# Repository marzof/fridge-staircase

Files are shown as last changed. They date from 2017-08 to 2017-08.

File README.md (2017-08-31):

Project for a staircase containing a fridge
-------

This repository contains all the files we made in order to build the staircase you see in the picture.



Every .fcstd file ([FreeCAD](https://www.freecadweb.org/) file) contains a 3d model of a part of the stair. Some of them contains an assemblage of parts as you can see in the dependency list at the end of this document (we used the [Assembly2 plugin](https://github.com/hamish2014/FreeCAD_assembly2)).

Drawing layout in *A101_assembled_stair.fcstd* and *A721_double_beam.fcstd* may not work correctly due to the excessive complexity of the board.
Because of that we decided, for the boards *A731*, *A732* and *A733* to compose the layout drawings into another software (we used [QCAD](http://qcad.org/en/)).

The workflow was:

1. model simple parts of the object in *FreeCAD*
2. render the drawing of the parts in *TechDraw* workbench. Here we set the point of view, the scale of the drawing, the width and the type of lines.
3. export the drawing in SVG (the dxf exporter doesn't seem to work very well)
4. convert the svg drawing in a series of dxf files using the [fc2dxf script](https://github.com/marzof/scripts/blob/master/fc2dxf.py): at the end you'll get a file for every style of line (visible, hidden, thick, thin...)
5. compose the board in a CAD software: add the title block, the dimensions, the annotations, etc...

You can find more pictures and infos [here](http://softwareliberoperlarchitettura.mfarchitetti.it/en_US/2017/08/31/progetto-per-una-scala-un-test-riuscito-per-un-software-open-source-per-la-progettazione-param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)

List of dependencies
----------

 - A101_assembled_stair.fcstd
	-  A712_fridge_box.fcstd
	-  step.fcstd
	-  plate.fcstd
	-  beam.fcstd
	-  railing_element.fcstd
	-  beam_plate.fcstd
	-  railing_last_element.fcstd
	-  railing_last_plate.fcstd
	-  railing_first_element.fcstd
	-  beam_ground_plate.fcstd
 - A711_fridge_box_panels.fcstd
	-  stair_profile.fcstd
	-  step.fcstd
	-  double_beam.fcstd
	-  fridge_box_door.fcstd
 - A712_fridge_box.fcstd
	-  fridge_box_door.fcstd
	-  A711_fridge_box_panels.fcstd
	-  fridge_box_door.fcstd
 - A721_double_beam.fcstd
	-  beam.fcstd
	-  A711_fridge_box_panels.fcstd
	-  stair_profile.fcstd
	-  step.fcstd
	-  beam_plate.fcstd
	-  fridge_box_door.fcstd
	-  railing_plate.fcstd
	-  plate.fcstd
 - all.fcstd
	-  double_beam.fcstd
	-  fasteners.fcstd
	-  railing_plate.fcstd
	-  railing_dist.fcstd
	-  railing_eyelet.fcstd
	-  railing_fasteners.fcstd
	-  ropes.fcstd
	-  step.fcstd
	-  handrail_holder.fcstd
	-  handrail.fcstd
	-  railing_wood.fcstd
	-  A711_fridge_box_panels.fcstd
	-  fridge_box_door.fcstd
	-  handrail_holder.fcstd
	-  railing_eyelet.fcstd
	-  railing_last_wood.fcstd
	-  stair_profile.fcstd
	-  room.fcstd
	-  plate.fcstd
	-  railing_last_steel.fcstd
	-  railing_plate.fcstd
	-  railing_dist.fcstd
	-  railing_eyelet.fcstd
	-  railing_fasteners.fcstd
	-  handrail_holder.fcstd
	-  railing_wood.fcstd
	-  handrail.fcstd
 - beam.fcstd
	-  stair_profile.fcstd
	-  step.fcstd
 - beam_ground_plate.fcstd
 - beam_plate.fcstd
	-  A711_fridge_box_panels.fcstd
	-  step.fcstd
	-  stair_profile.fcstd
	-  double_beam.fcstd
 - double_beam.fcstd
	-  beam.fcstd
	-  A711_fridge_box_panels.fcstd
	-  stair_profile.fcstd
	-  step.fcstd
	-  beam_plate.fcstd
	-  fridge_box_door.fcstd
	-  railing_plate.fcstd
	-  plate.fcstd
 - fasteners.fcstd
	-  double_beam.fcstd
	-  railing_plate.fcstd
 - fridge_box_door.fcstd
 - handrail.fcstd
 - handrail_holder.fcstd
	-  railing_eyelet.fcstd
 - loft_handrail.fcstd
 - loft_handrail_holder.fcstd
 - loft_railing_element.fcstd
	-  room.fcstd
 - loft_railing.fcstd
	-  handrail.fcstd
	-  A711_fridge_box_panels.fcstd
	-  fridge_box_door.fcstd
	-  handrail_holder.fcstd
	-  railing_eyelet.fcstd
	-  railing_last_wood.fcstd
	-  room.fcstd
	-  railing_last_steel.fcstd
	-  loft_railing_element.fcstd
	-  loft_ropes.fcstd
	-  railing_element.fcstd
	-  ropes.fcstd
	-  railing_last.fcstd
 - loft_ropes.fcstd
 - plate.fcstd
	-  step.fcstd
 - railing_dist.fcstd
	-  railing_eyelet.fcstd
 - railing_element.fcstd
	-  double_beam.fcstd
	-  fasteners.fcstd
	-  railing_plate.fcstd
	-  railing_dist.fcstd
	-  railing_eyelet.fcstd
	-  railing_fasteners.fcstd
	-  ropes.fcstd
	-  step.fcstd
	-  handrail_holder.fcstd
	-  handrail.fcstd
	-  railing_wood.fcstd
	-  A711_fridge_box_panels.fcstd
	-  fridge_box_door.fcstd
	-  handrail_holder.fcstd
	-  railing_eyelet.fcstd
	-  railing_last_wood.fcstd
	-  stair_profile.fcstd
	-  room.fcstd
	-  plate.fcstd
	-  room.fcstd
	-  railing_last_steel.fcstd
 - railing_eyelet.fcstd
 - railing_fasteners.fcstd
 - railing_last.fcstd
	-  handrail_holder.fcstd
	-  railing_eyelet.fcstd
	-  railing_last_wood.fcstd
	-  railing_last_steel.fcstd
 - railing_last_steel.fcstd
	-  railing_eyelet.fcstd
	-  room.fcstd
	-  loft_railing_element.fcstd
 - railing_last_wood.fcstd
	-  double_beam.fcstd
	-  railing_last_steel.fcstd
 - railing_plate.fcstd
	-  double_beam.fcstd
 - railing_wood.fcstd
 - room.fcstd
 - ropes.fcstd
	-  railing_eyelet.fcstd
 - stair_profile.fcstd
 - step.fcstd
	-  stair_profile.fcstd

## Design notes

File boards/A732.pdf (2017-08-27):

1 | 2 | 3 | 4 | 5 | 6 | 7 | 8 | 9 | 10 | 11 FEDCBAGH | FEDCABGH 1 | 2 | 3 | 4 | 5 | 6 | 7 | 8 | 9 | 10 | PROGETTO: | DATA COMMITTENTE: ARCHITETTI: OGGETTO: TAVOLA NO.: | DI SCALA: FORMATO: DATA: REV: LUOGO: NOTE: NOME FILE: VERSIONE mf architetti Milano - Italy Via Lario 13/A _ +39(0)269901138 mfarchitetti.it _ mail@mfarchitetti.it CASA VACANZE A SESTRI SCALA INTERNA MARZIA FILATRELLA MARCO FERRARA DETTAGLI PARAPETTO - A732.DXF 1.0 | 2017.05.11 6 | 7 (nd) A732 2017/05/11 1.0 | 1:5;1:10 A2 0 | 1/5 | 1/2 | 25cm;50cm 2850 | 865 1100 1100 1100 | 850 630 630 615 | 615 | 615 | 630 | 165 | 315 | 45 115 | 55 Il supporto per l'ultimo montante avverrà attraverso una piastra metallica a "L" fissata al soppalco durante la fase di posa in opera | ULTIMO MONTANTE Listelli in legno sp. 20mm no. pz. 1 coppia scala 1:5 SUPPORTO ULTIMO MONTANTE Piastra in acciaio sp. 6mm e sp. 10mm no. pz. 1 scala 1:5 | Foro posteriore filettato per occhiello reggi-cavi ³².5 45 180 45 180 45 180 45 112.5 | 865 50 | 50 ⁸⁶⁵

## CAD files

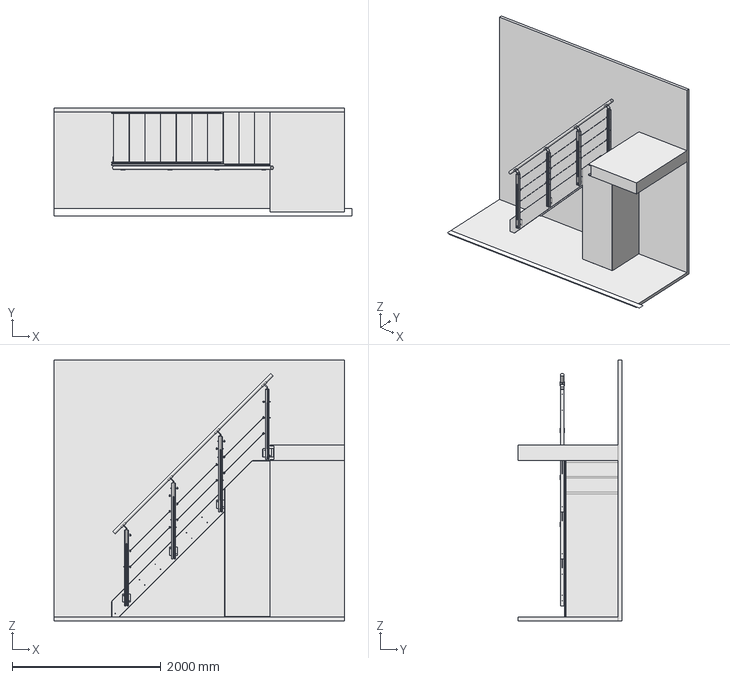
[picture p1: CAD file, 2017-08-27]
A101_assembled_stair.fcstd
4000.0 x 1445.0 x 3500.0 mm
all
Rectangle002

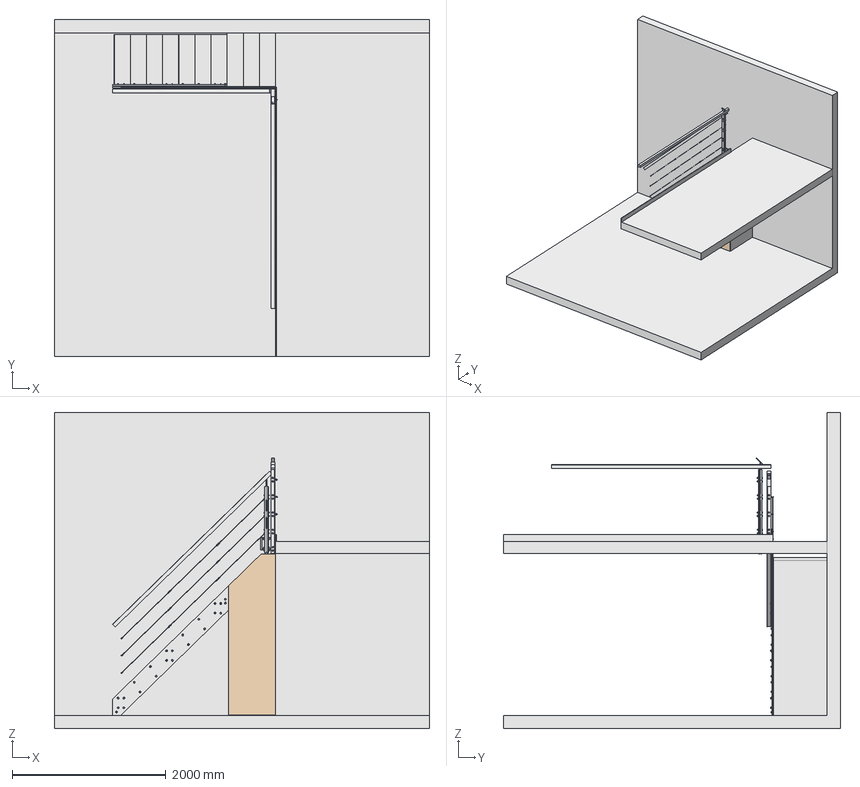
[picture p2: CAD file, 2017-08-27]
all.fcstd
4875.0 x 4375.4 x 4112.1 mm
double_beam_01
fasteners_01
step_01
handrail_01
ropes
fridge_box_panels_01
fridge_box_door_01
last_railing
room_01
plate_01
handrail_002

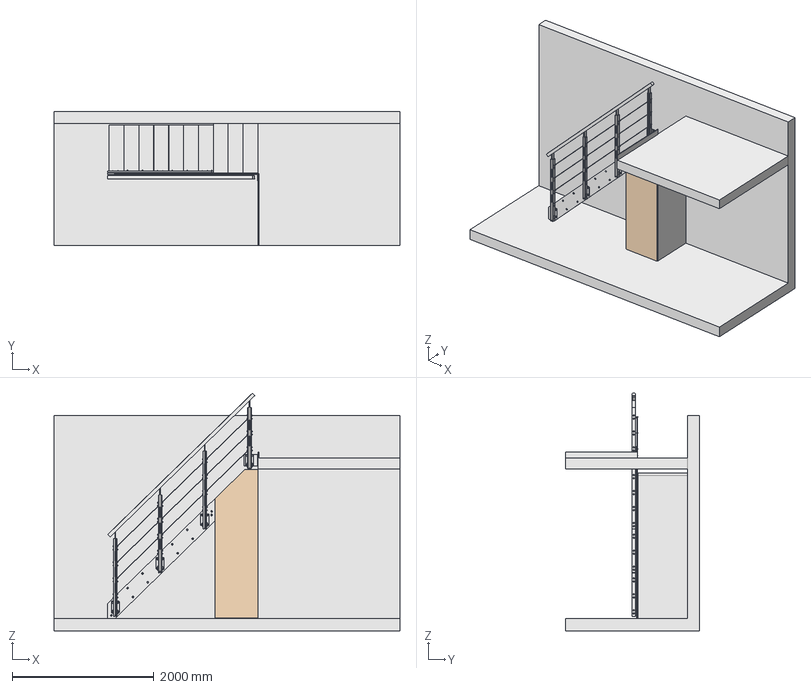
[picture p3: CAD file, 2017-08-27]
views/railing_last_element_rear.fcstd
4875.0 x 1890.4 x 3348.2 mm
double_beam_01
fasteners_01
step_01
ropes
fridge_box_panels_01
fridge_box_door_01
plate_01
Cutted_room
handrail_01
last_railing

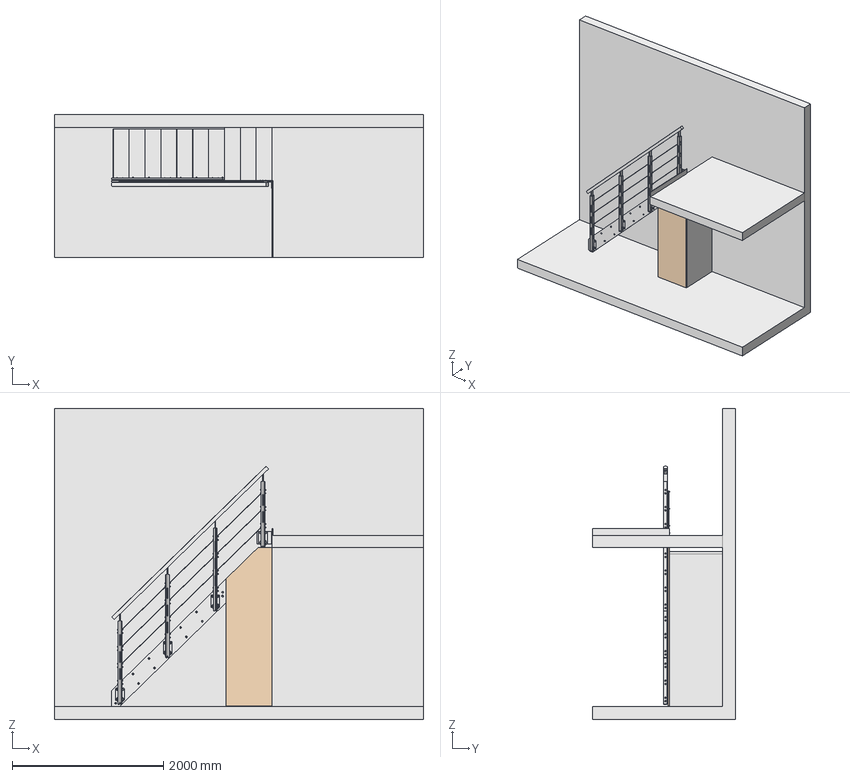
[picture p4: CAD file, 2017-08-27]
views/railing_element_rear.fcstd
4875.0 x 1890.4 x 4112.1 mm
double_beam_01
fasteners_01
step_01
ropes
fridge_box_panels_01
fridge_box_door_01
room_01
plate_01
handrail_01
last_railing

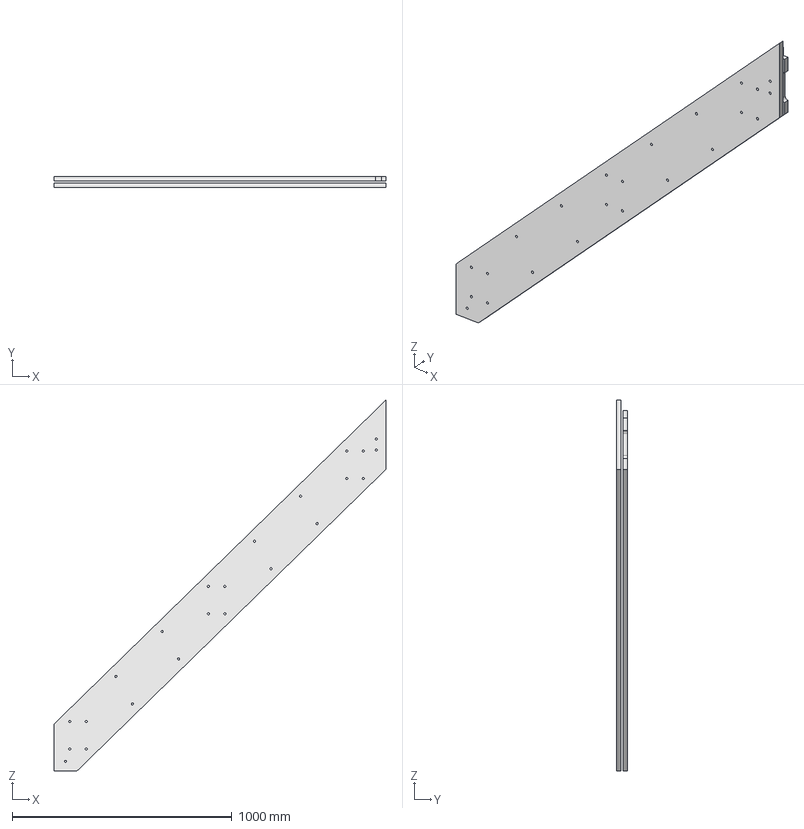
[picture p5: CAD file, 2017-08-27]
double_beam.fcstd
1510.0 x 50.0 x 1687.5 mm

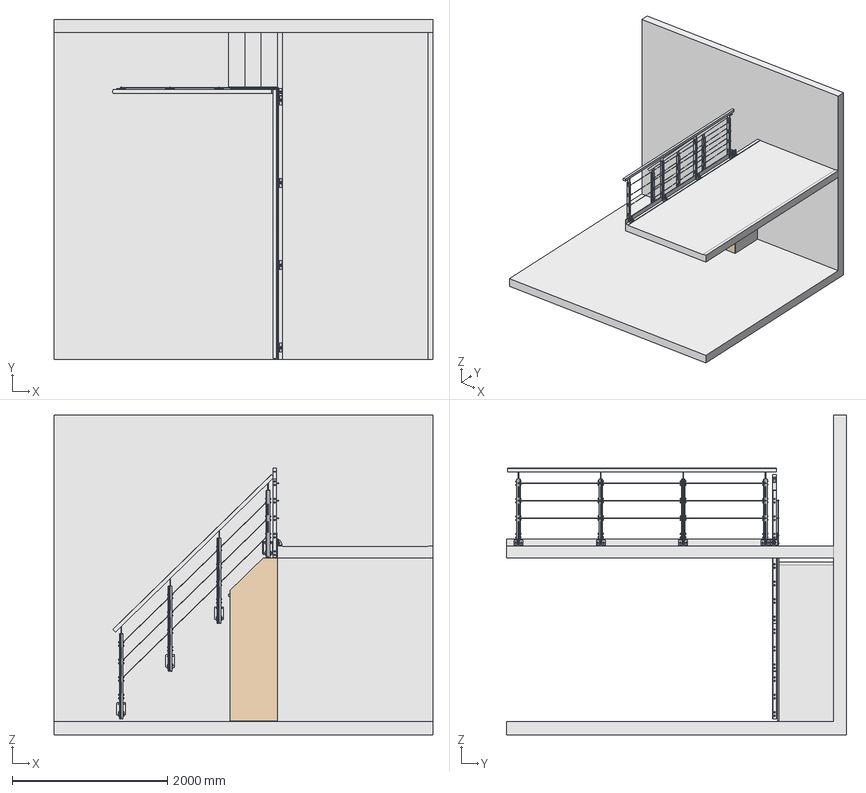
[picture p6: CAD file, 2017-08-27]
loft_railing.fcstd
4875.0 x 4375.4 x 4112.1 mm
loft_ropes_01
railing_element_01
room_01
fridge_box_door_01
fridge_box_panels_01
handrail_01
railing_last_01

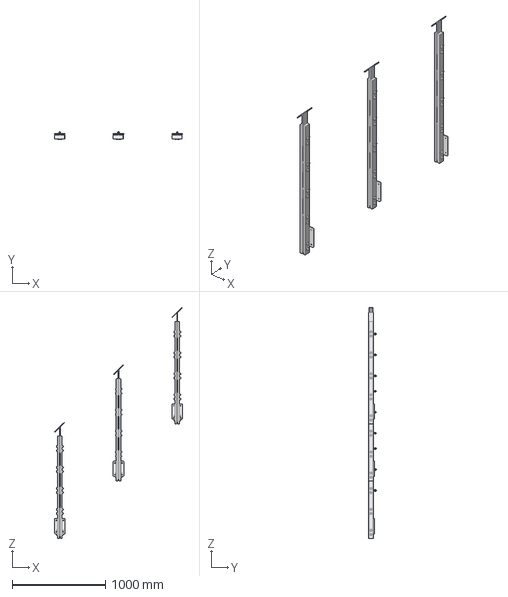
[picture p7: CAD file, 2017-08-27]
railing_element.fcstd
1375.4 x 83.2 x 2479.1 mm

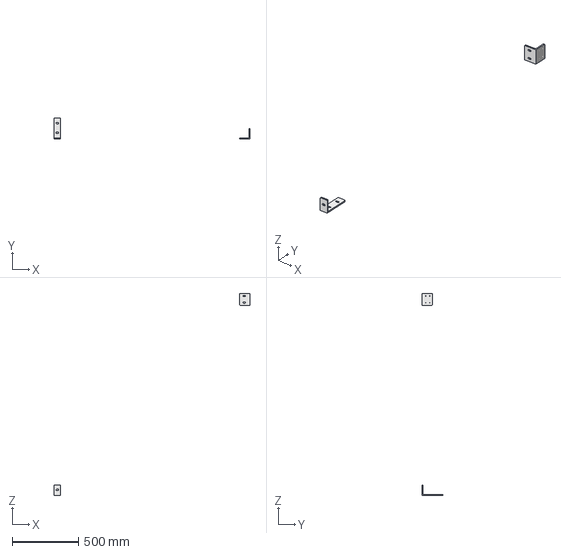
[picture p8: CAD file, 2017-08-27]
beam_plate.fcstd
1482.8 x 160.0 x 1530.0 mm

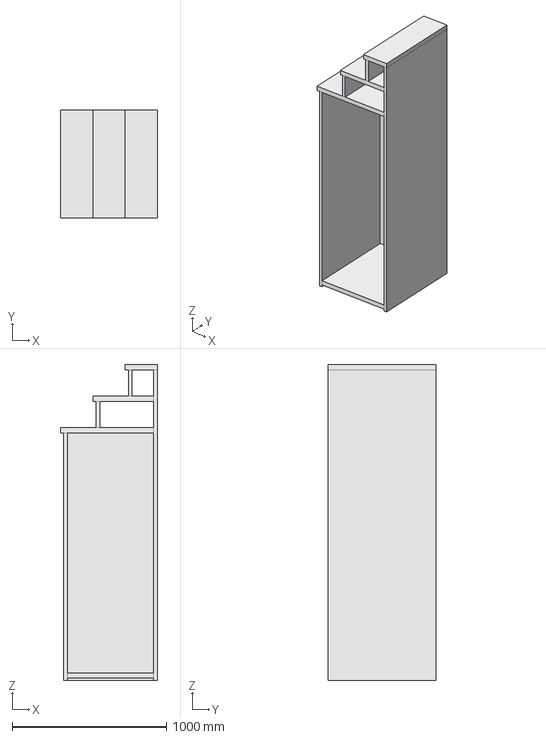
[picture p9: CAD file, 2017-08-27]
A711_fridge_box_panels.fcstd
630.0 x 700.0 x 2050.0 mm

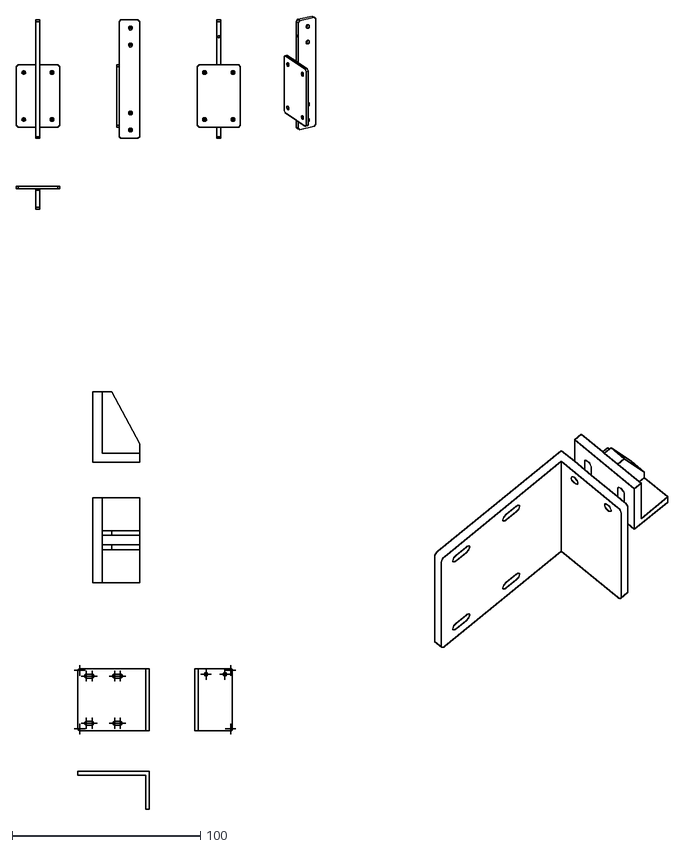
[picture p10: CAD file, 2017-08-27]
railing_last_elements_fll.dxf
345.8 x 420.8

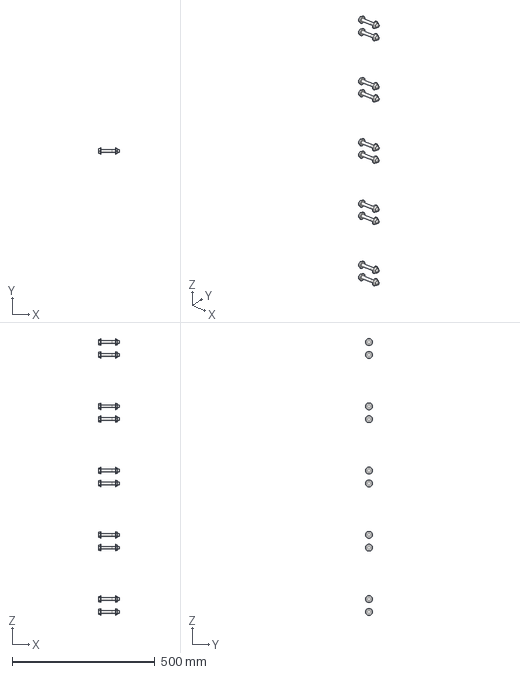
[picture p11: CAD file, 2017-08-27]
railing_fasteners.fcstd
72.4 x 25.0 x 970.0 mm

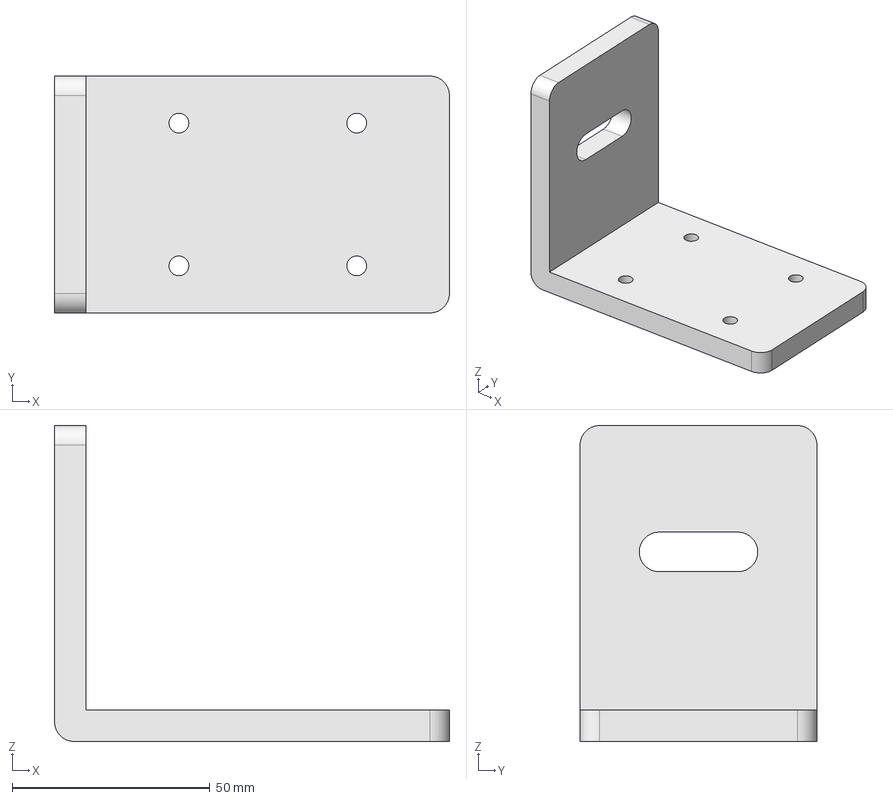
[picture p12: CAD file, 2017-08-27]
beam_ground_plate.fcstd
100.0 x 60.0 x 80.0 mm

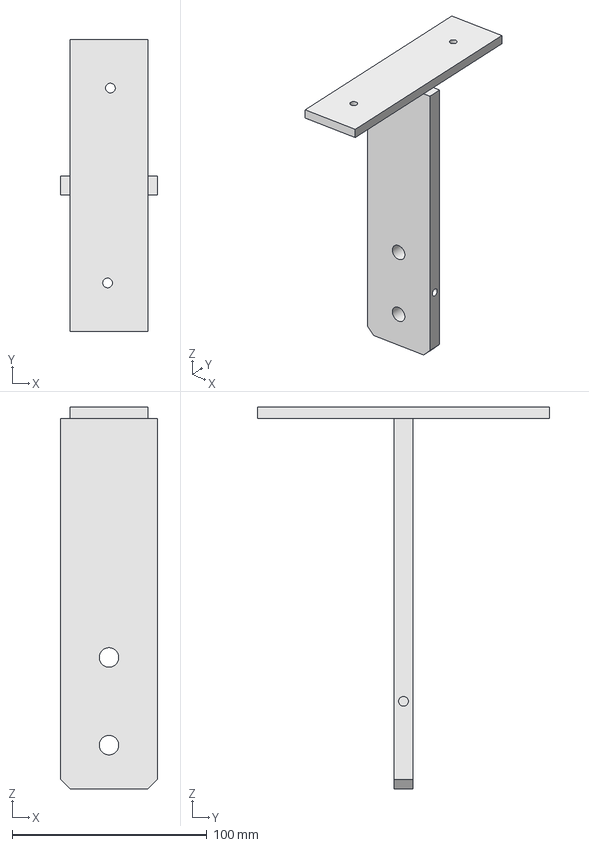
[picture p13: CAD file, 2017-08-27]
loft_handrail_holder.fcstd
50.0 x 150.0 x 196.0 mm

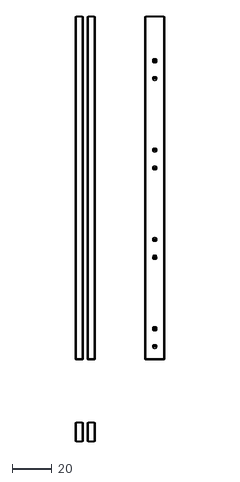
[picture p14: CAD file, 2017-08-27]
railing_last_wood_vsb.dxf
45.0 x 214.5

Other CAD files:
A721_double_beam.fcstd
A712_fridge_box.fcstd
railing_last_fixing_vsb.dxf
handrail_holder_vsb.dxf
A731.dxf
A732.dxf
A733.dxf
archive/eyelet.fcstd
archive/railing_first_element.fcstd
archive/railing_last_element.fcstd
beam.fcstd
fasteners.fcstd
fridge_box_door.fcstd
handrail.fcstd
handrail_holder.fcstd
handrail_holder_hdn.dxf
loft_handrail.fcstd
loft_railing_element.fcstd
loft_ropes.fcstd
plate.fcstd
railing_dist.fcstd
railing_dist_hdn.dxf
railing_dist_vsb.dxf
railing_eyelet.fcstd
railing_front_hdn.dxf
railing_front_vsb.dxf
railing_last.fcstd
railing_last_elements_hdn.dxf
railing_last_elements_vsb.dxf
railing_last_fixing_hdn.dxf
railing_last_plate_hdn.dxf
railing_last_plate_vsb.dxf
railing_last_steel.fcstd
railing_last_wood.fcstd
railing_last_wood_hdn.dxf
railing_plate.fcstd
railing_plate_hdn.dxf
railing_plate_vsb.dxf
railing_rear_hdn.dxf
railing_rear_vsb.dxf
railing_wood.fcstd
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

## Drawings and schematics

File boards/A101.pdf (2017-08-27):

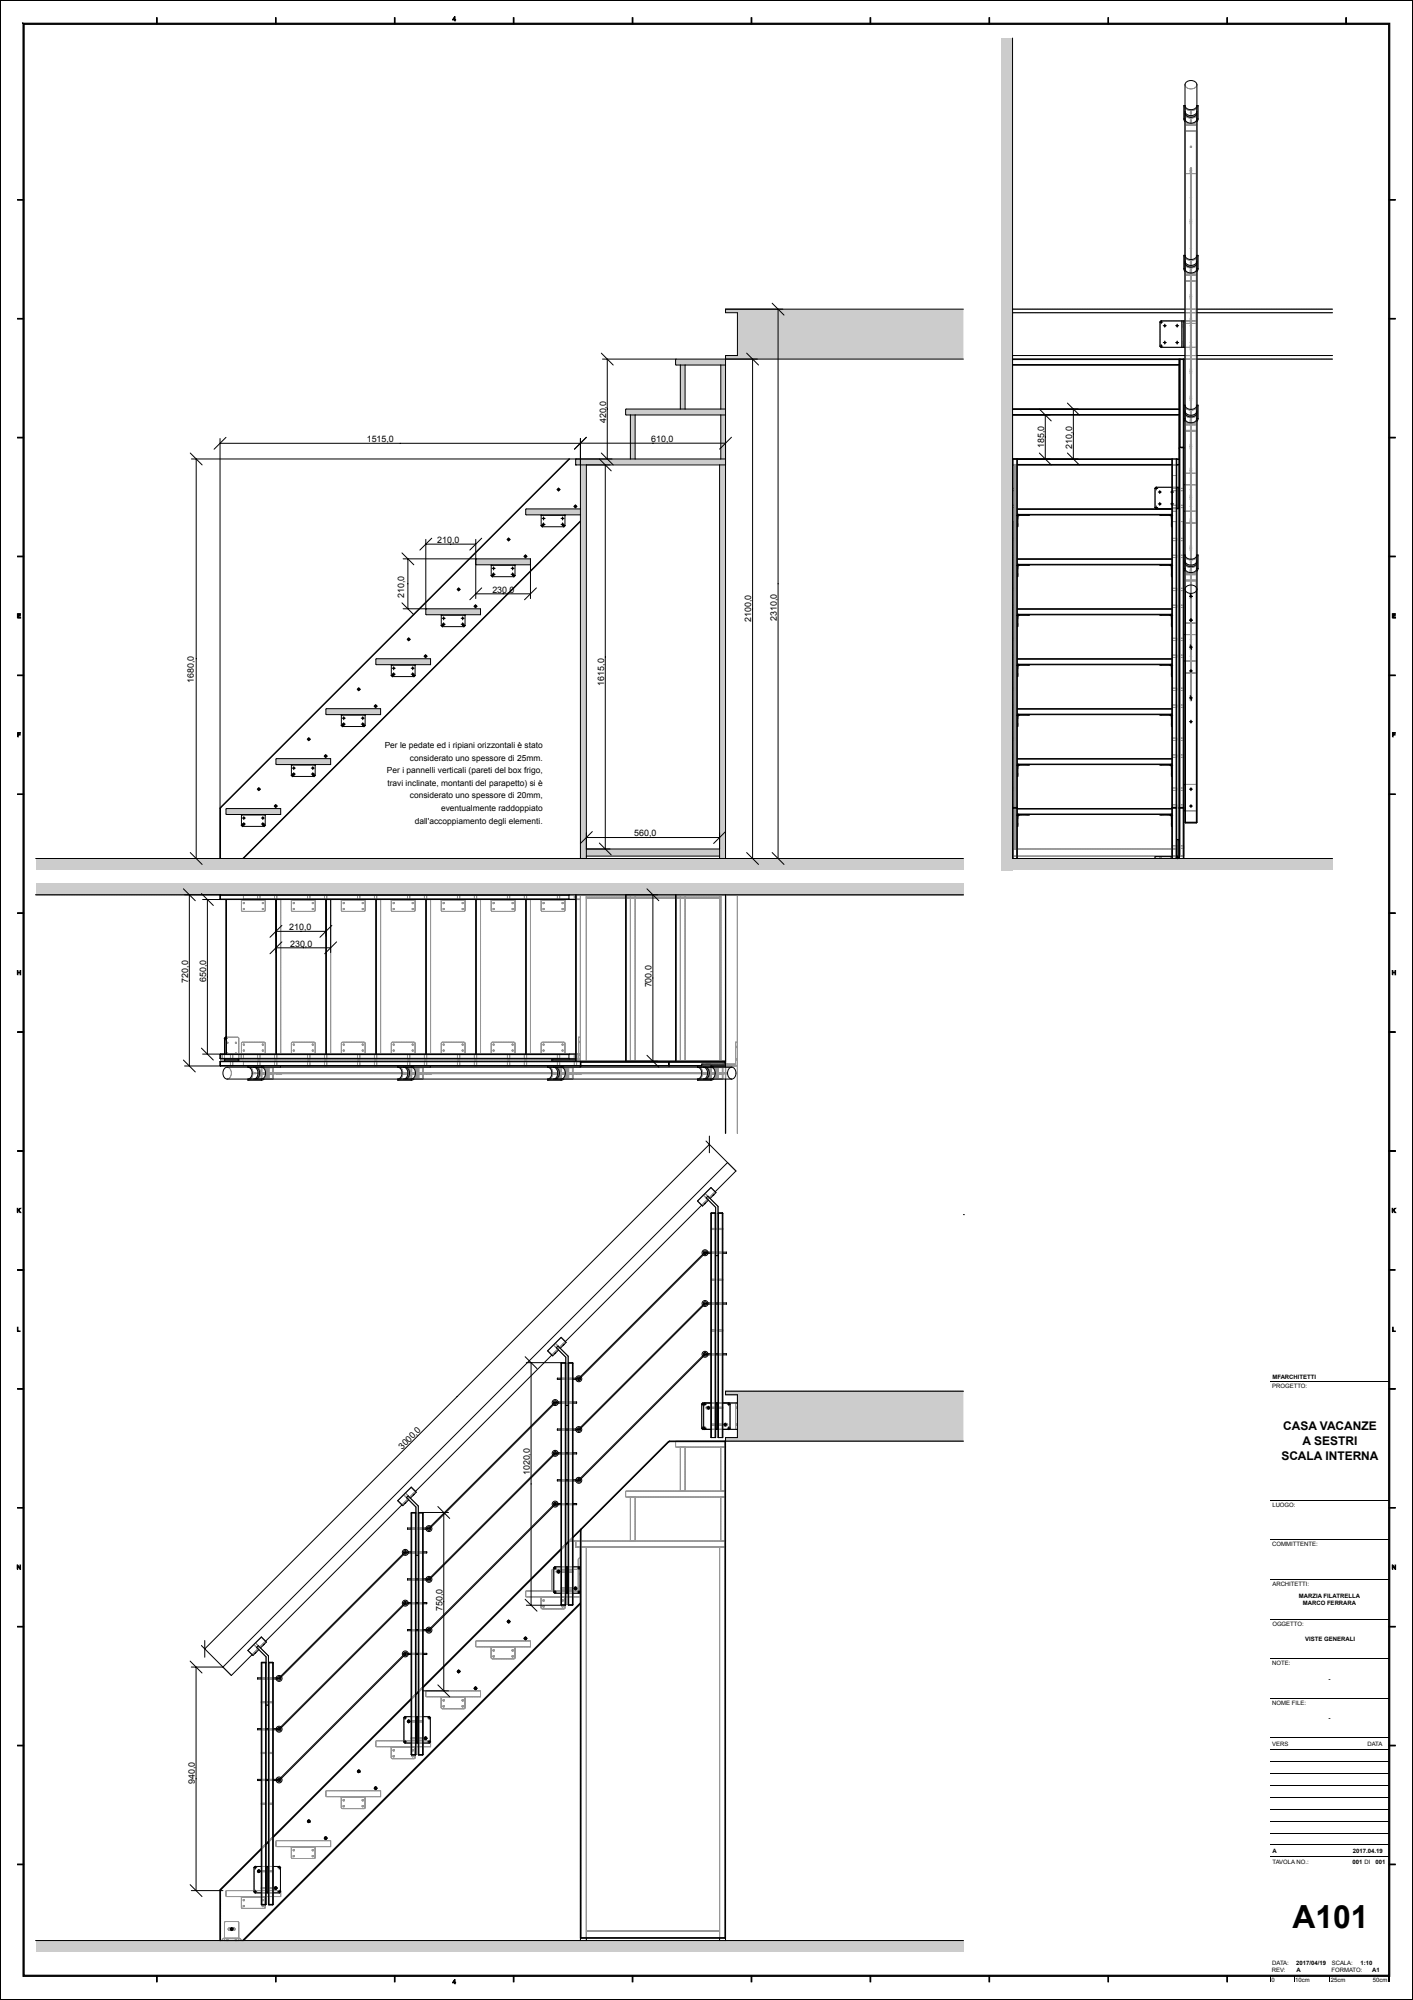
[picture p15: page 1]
PROGETTO:; DATA; COMMITTENTE:; ARCHITETTI:; OGGETTO:; TAVOLA NO.:; SCALA: FORMATO:; DATA: REV:; LUOGO:; NOTE:; NOME FILE:; VERS; MFARCHITETTI; VISTE GENERALI; MARZIA FILATRELLA MARCO FERRARA; CASA VACANZE A SESTRI SCALA INTERNA

Per le pedate ed i ripiani orizzontali è stato
considerato uno spessore di 25mm.
Per i pannelli verticali (pareti del box frigo,
travi inclinate, montanti del parapetto) si è
considerato uno spessore di 20mm,

eventualmente raddoppiato
dall'accoppiamento degli elementi.

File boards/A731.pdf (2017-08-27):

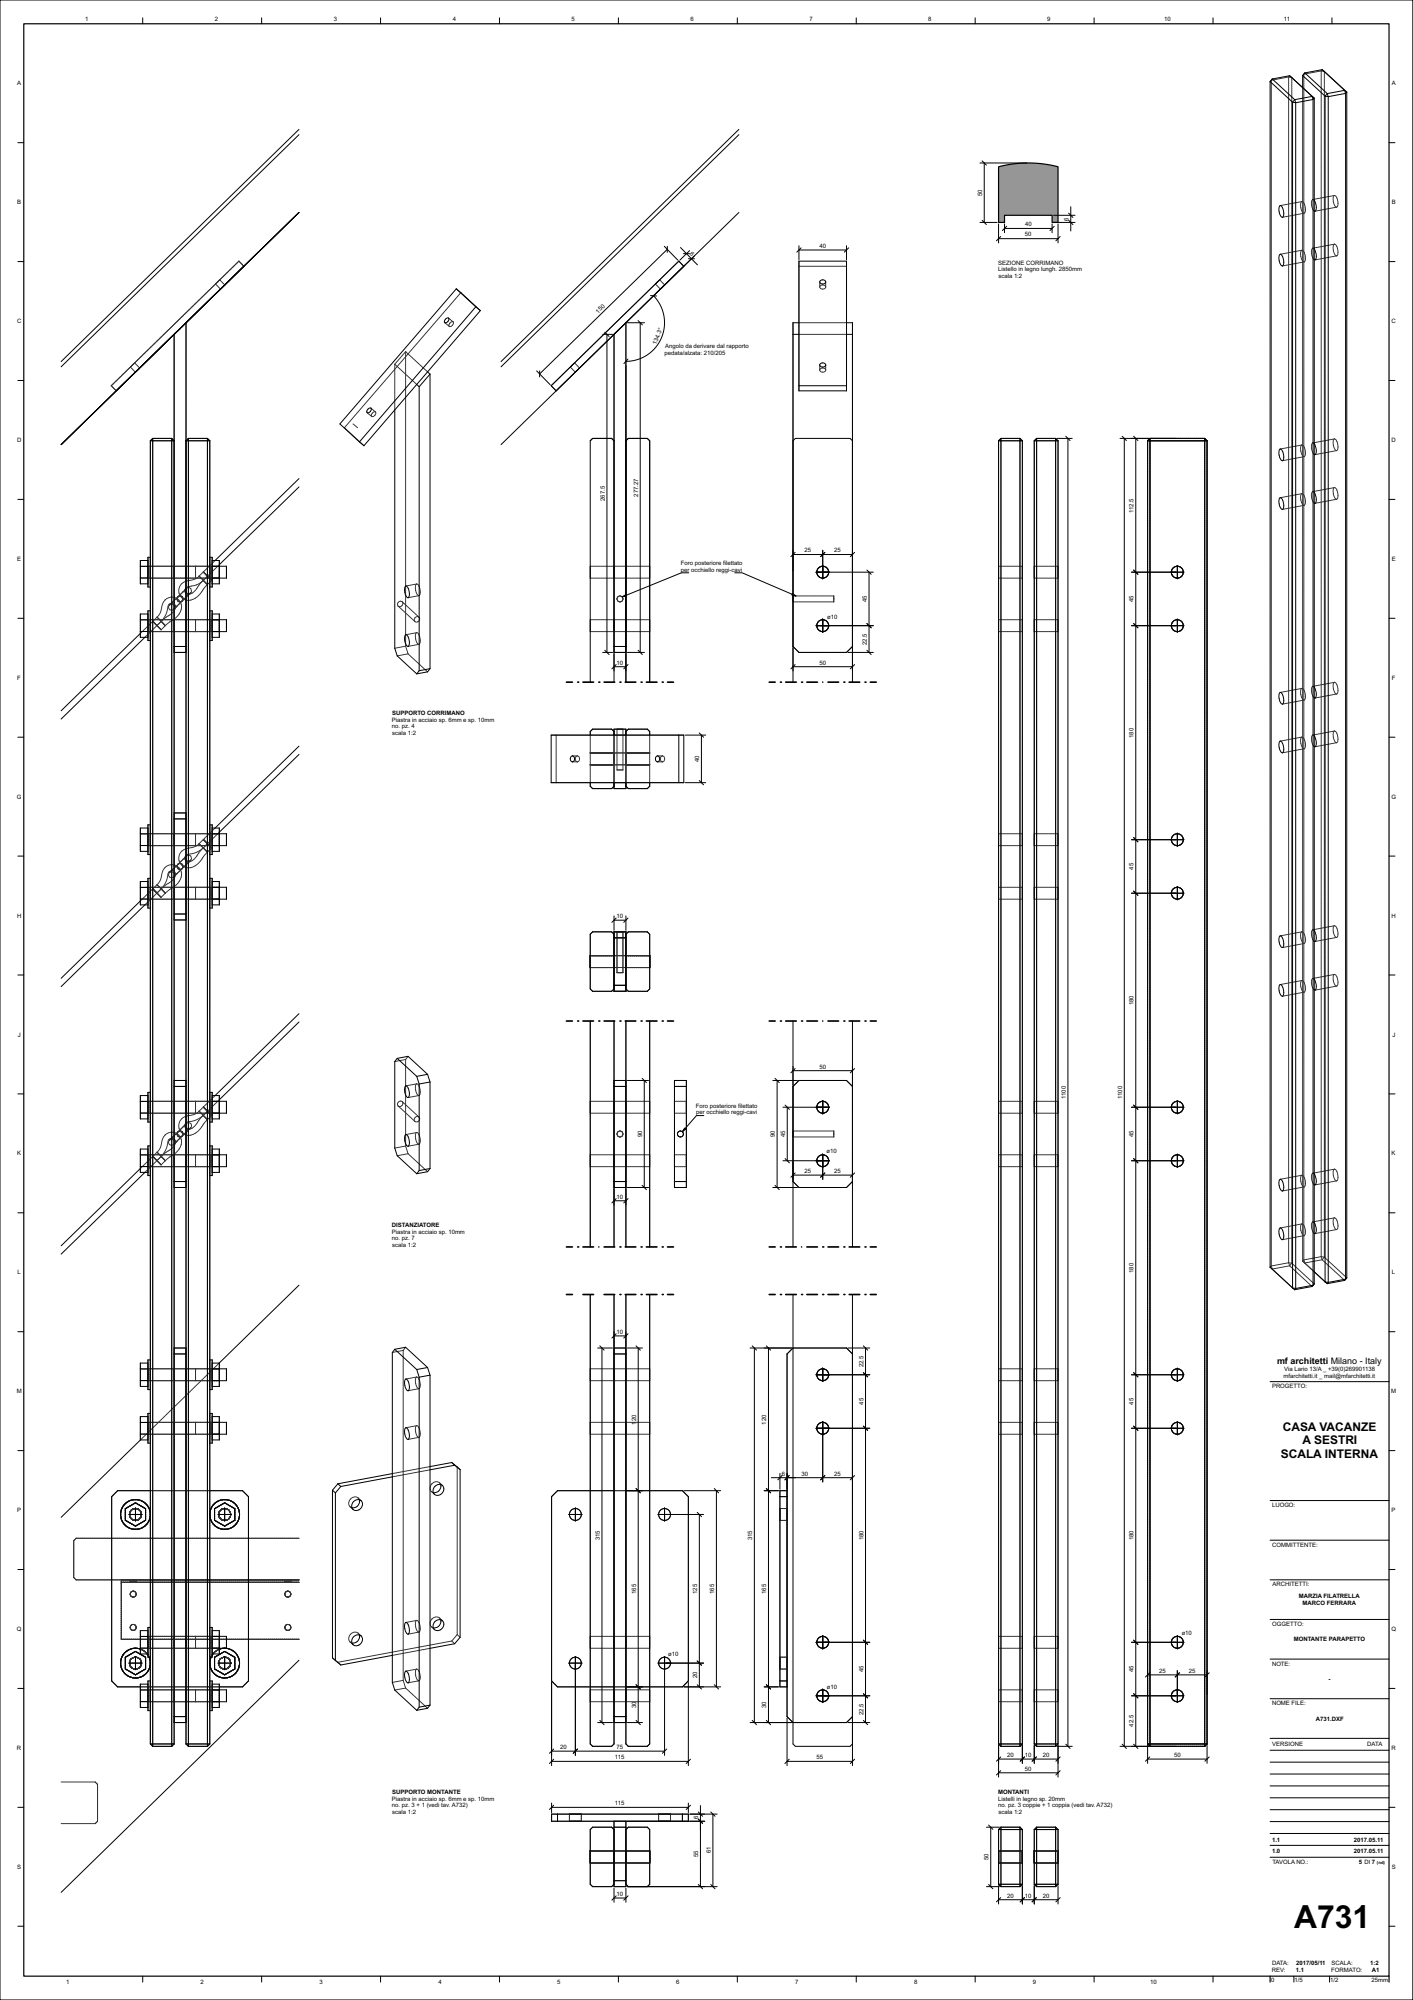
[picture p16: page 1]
PROGETTO:; DATA; TAVOLA NO.:; LUOGO:; CASA VACANZE A SESTRI SCALA INTERNA; MONTANTE PARAPETTO; - A731.DXF

SEZIONE CORRIMANO
Listello in legno lungh. 2850mm
scala 1:2

Angolo da derivare dal rapporto
pedata/alzata: 210/205

Foro posteriore filettato
per occhiello reggi-cavi

SUPPORTO CORRIMANO
Piastra in acciaio sp. 6mm e sp. 10mm

DISTANZIATORE
Piastra in acciaio sp. 10mm

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

COMMITTENTE: ARCHITETTI: OGGETTO:

MARZIA FILATRELLA
MARCO FERRARA
NOTE: NOME FILE: VERSIONE

SUPPORTO MONTANTE
no. pz. 3 + 1 (vedi tav. A732) scala 1:2

MONTANTI
Listelli in legno sp. 20mm
no. pz. 3 coppie + 1 coppia (vedi tav. A732) scala 1:2

SCALA: FORMATO: DATA: REV:

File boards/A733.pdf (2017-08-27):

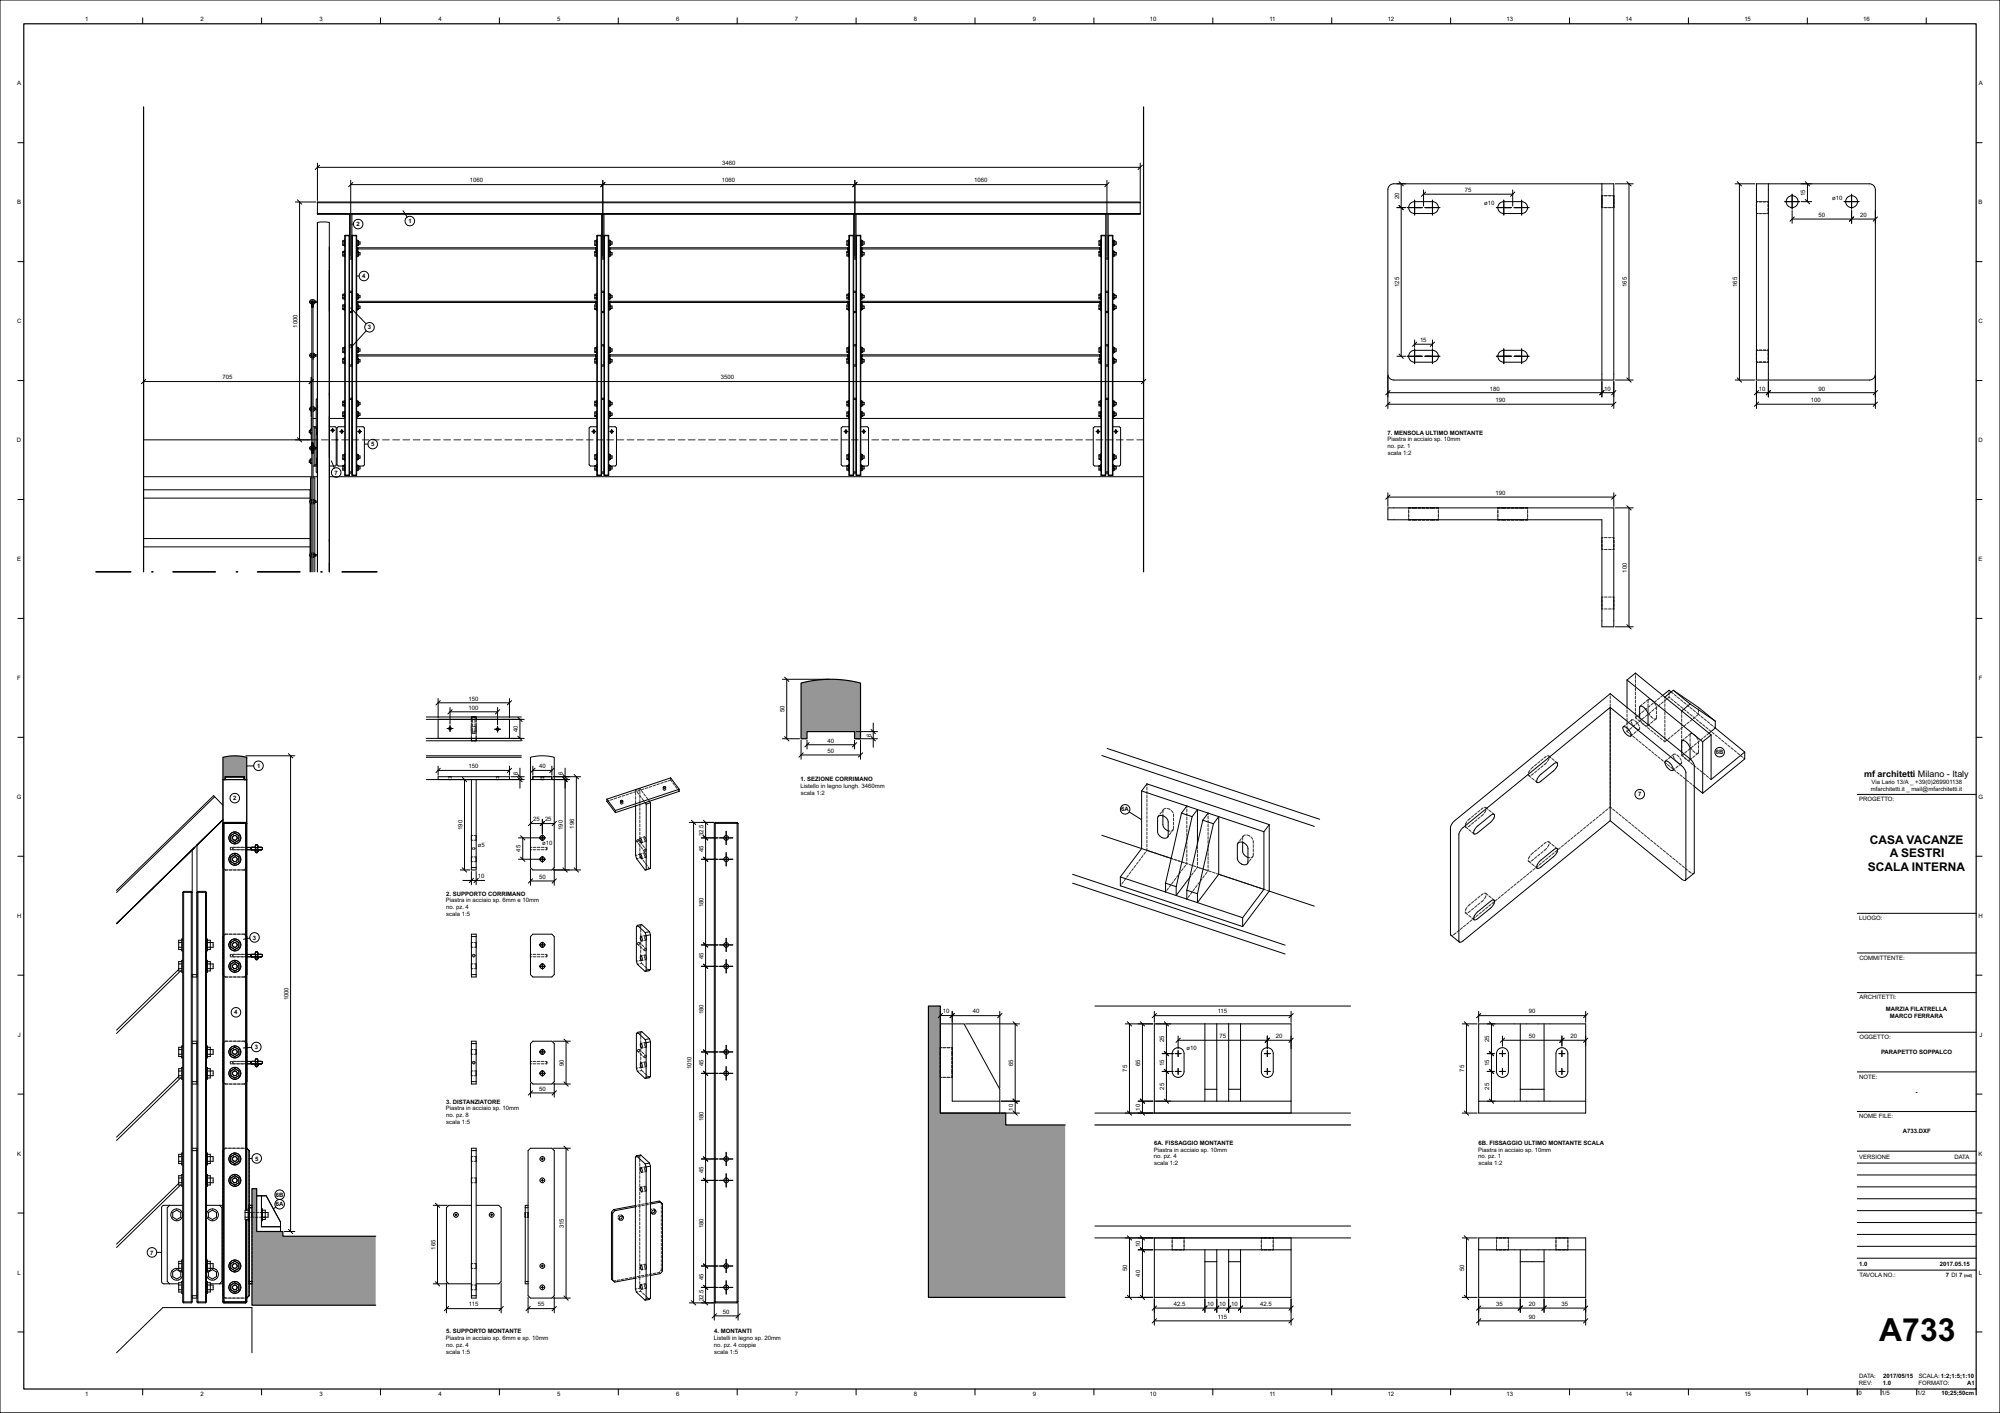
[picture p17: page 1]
PROGETTO:; DATA; TAVOLA NO.:; LUOGO:; CASA VACANZE A SESTRI SCALA INTERNA; PARAPETTO SOPPALCO; - A733.DXF

7. MENSOLA ULTIMO MONTANTE
Piastra in acciaio sp. 10mm
scala 1:2

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

1. SEZIONE CORRIMANO
Listello in legno lungh. 3460mm

2. SUPPORTO CORRIMANO
Piastra in acciaio sp. 6mm e 10mm
scala 1:5

COMMITTENTE: ARCHITETTI: OGGETTO:

MARZIA FILATRELLA
MARCO FERRARA
NOTE: NOME FILE: VERSIONE

3. DISTANZIATORE

6A. FISSAGGIO MONTANTE

6B. FISSAGGIO ULTIMO MONTANTE SCALA

5. SUPPORTO MONTANTE
Piastra in acciaio sp. 6mm e sp. 10mm

4. MONTANTI
Listelli in legno sp. 20mm
no. pz. 4 coppie

SCALA: FORMATO: DATA: REV:

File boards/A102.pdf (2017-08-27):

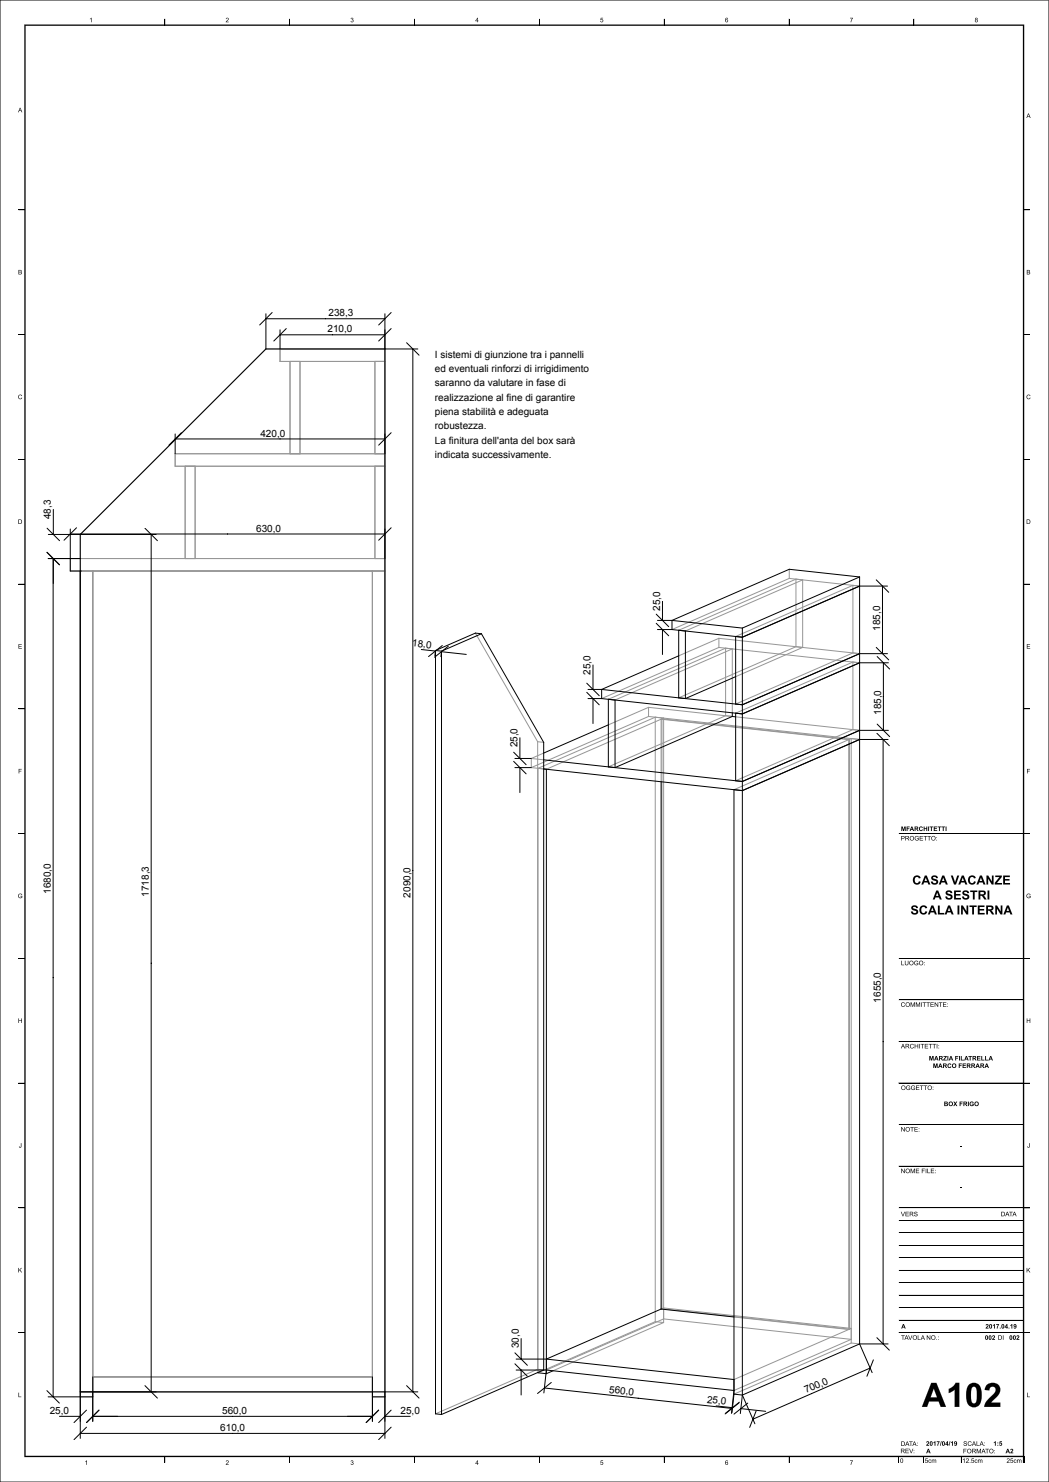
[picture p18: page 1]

I sistemi di giunzione tra i pannelli
ed eventuali rinforzi di irrigidimento
saranno da valutare in fase di
realizzazione al fine di garantire
piena stabilità e adeguata
robustezza.
La finitura dell'anta del box sarà
indicata successivamente.

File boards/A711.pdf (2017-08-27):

1

9

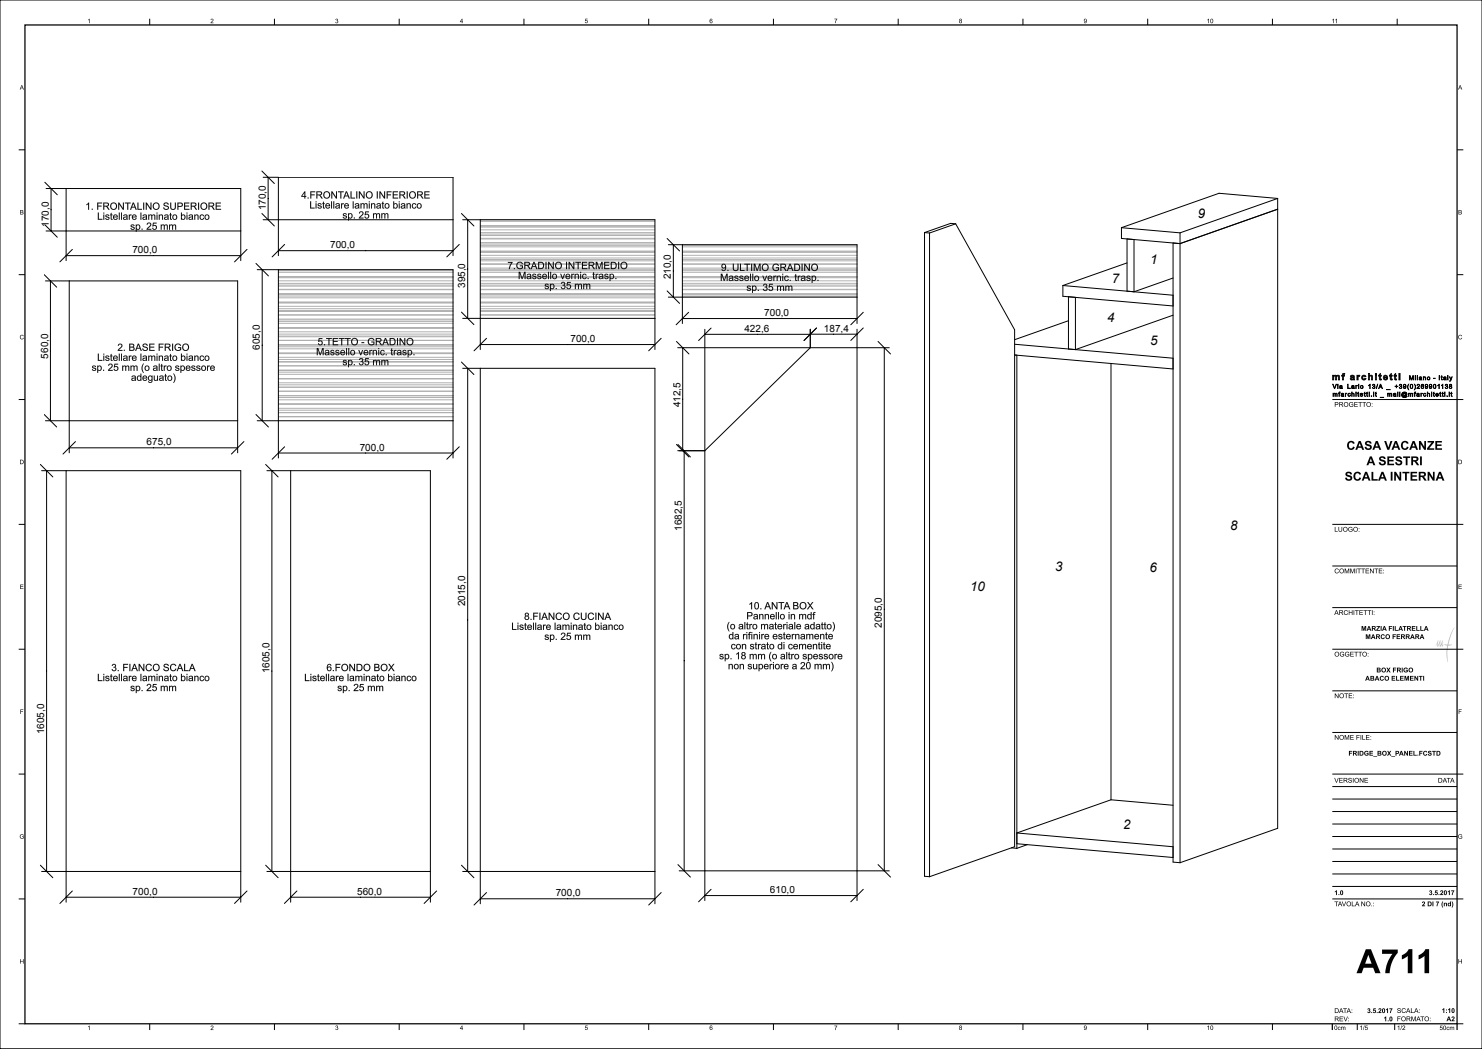
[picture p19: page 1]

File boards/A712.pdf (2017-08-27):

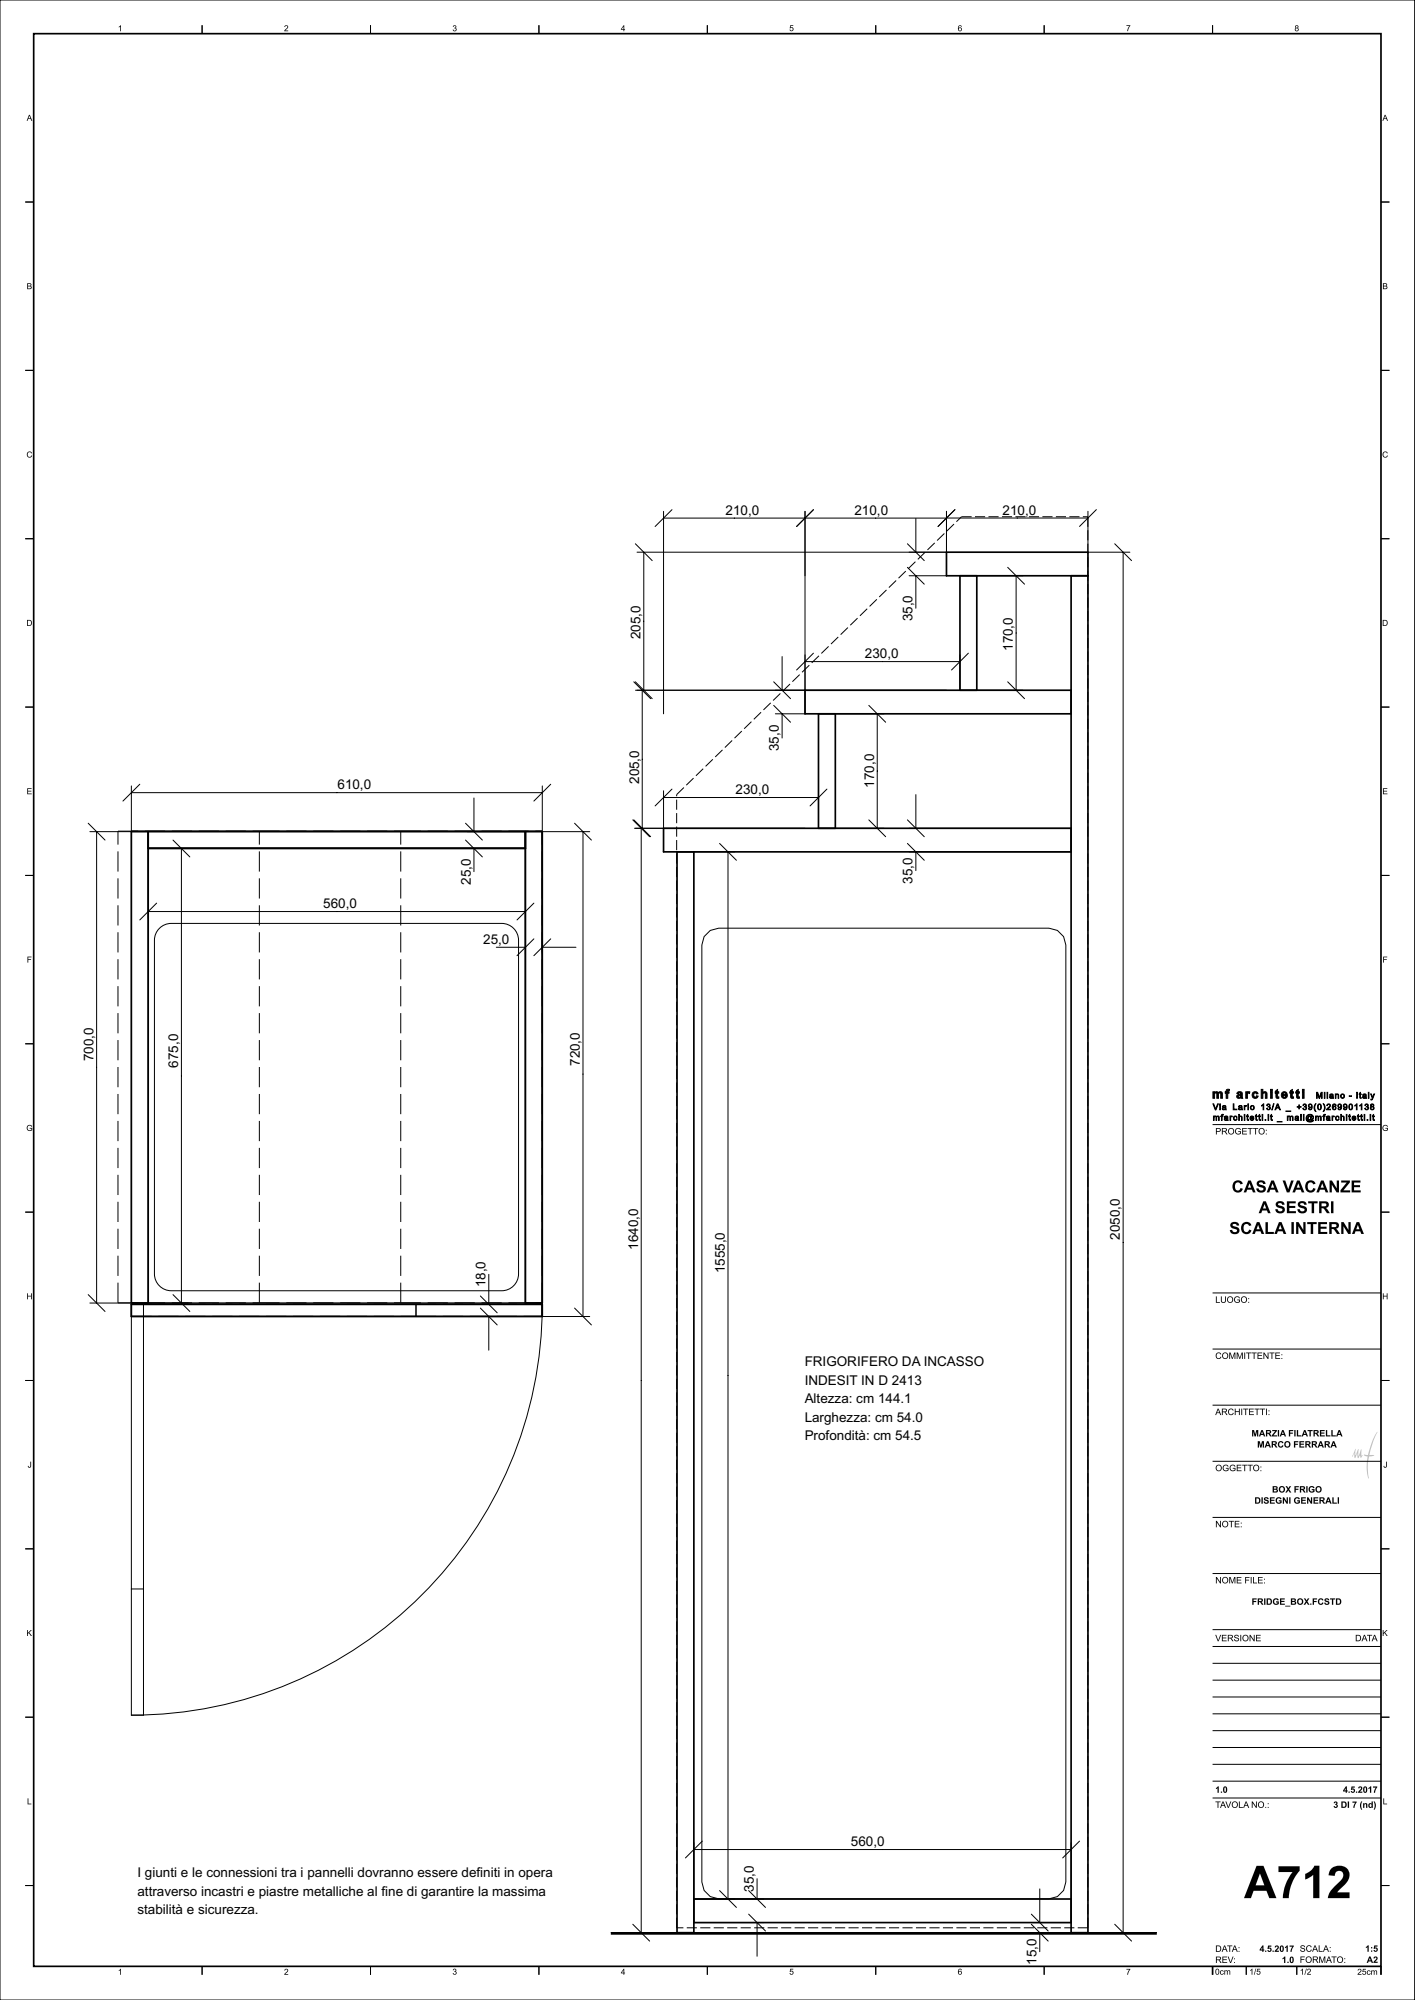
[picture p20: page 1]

FRIGORIFERO DA INCASSO
INDESIT IN D 2413
Altezza: cm 144.1
Larghezza: cm 54.0
Profondità: cm 54.5

I giunti e le connessioni tra i pannelli dovranno essere definiti in opera
attraverso incastri e piastre metalliche al fine di garantire la massima
stabilità e sicurezza.

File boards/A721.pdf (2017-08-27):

2
2

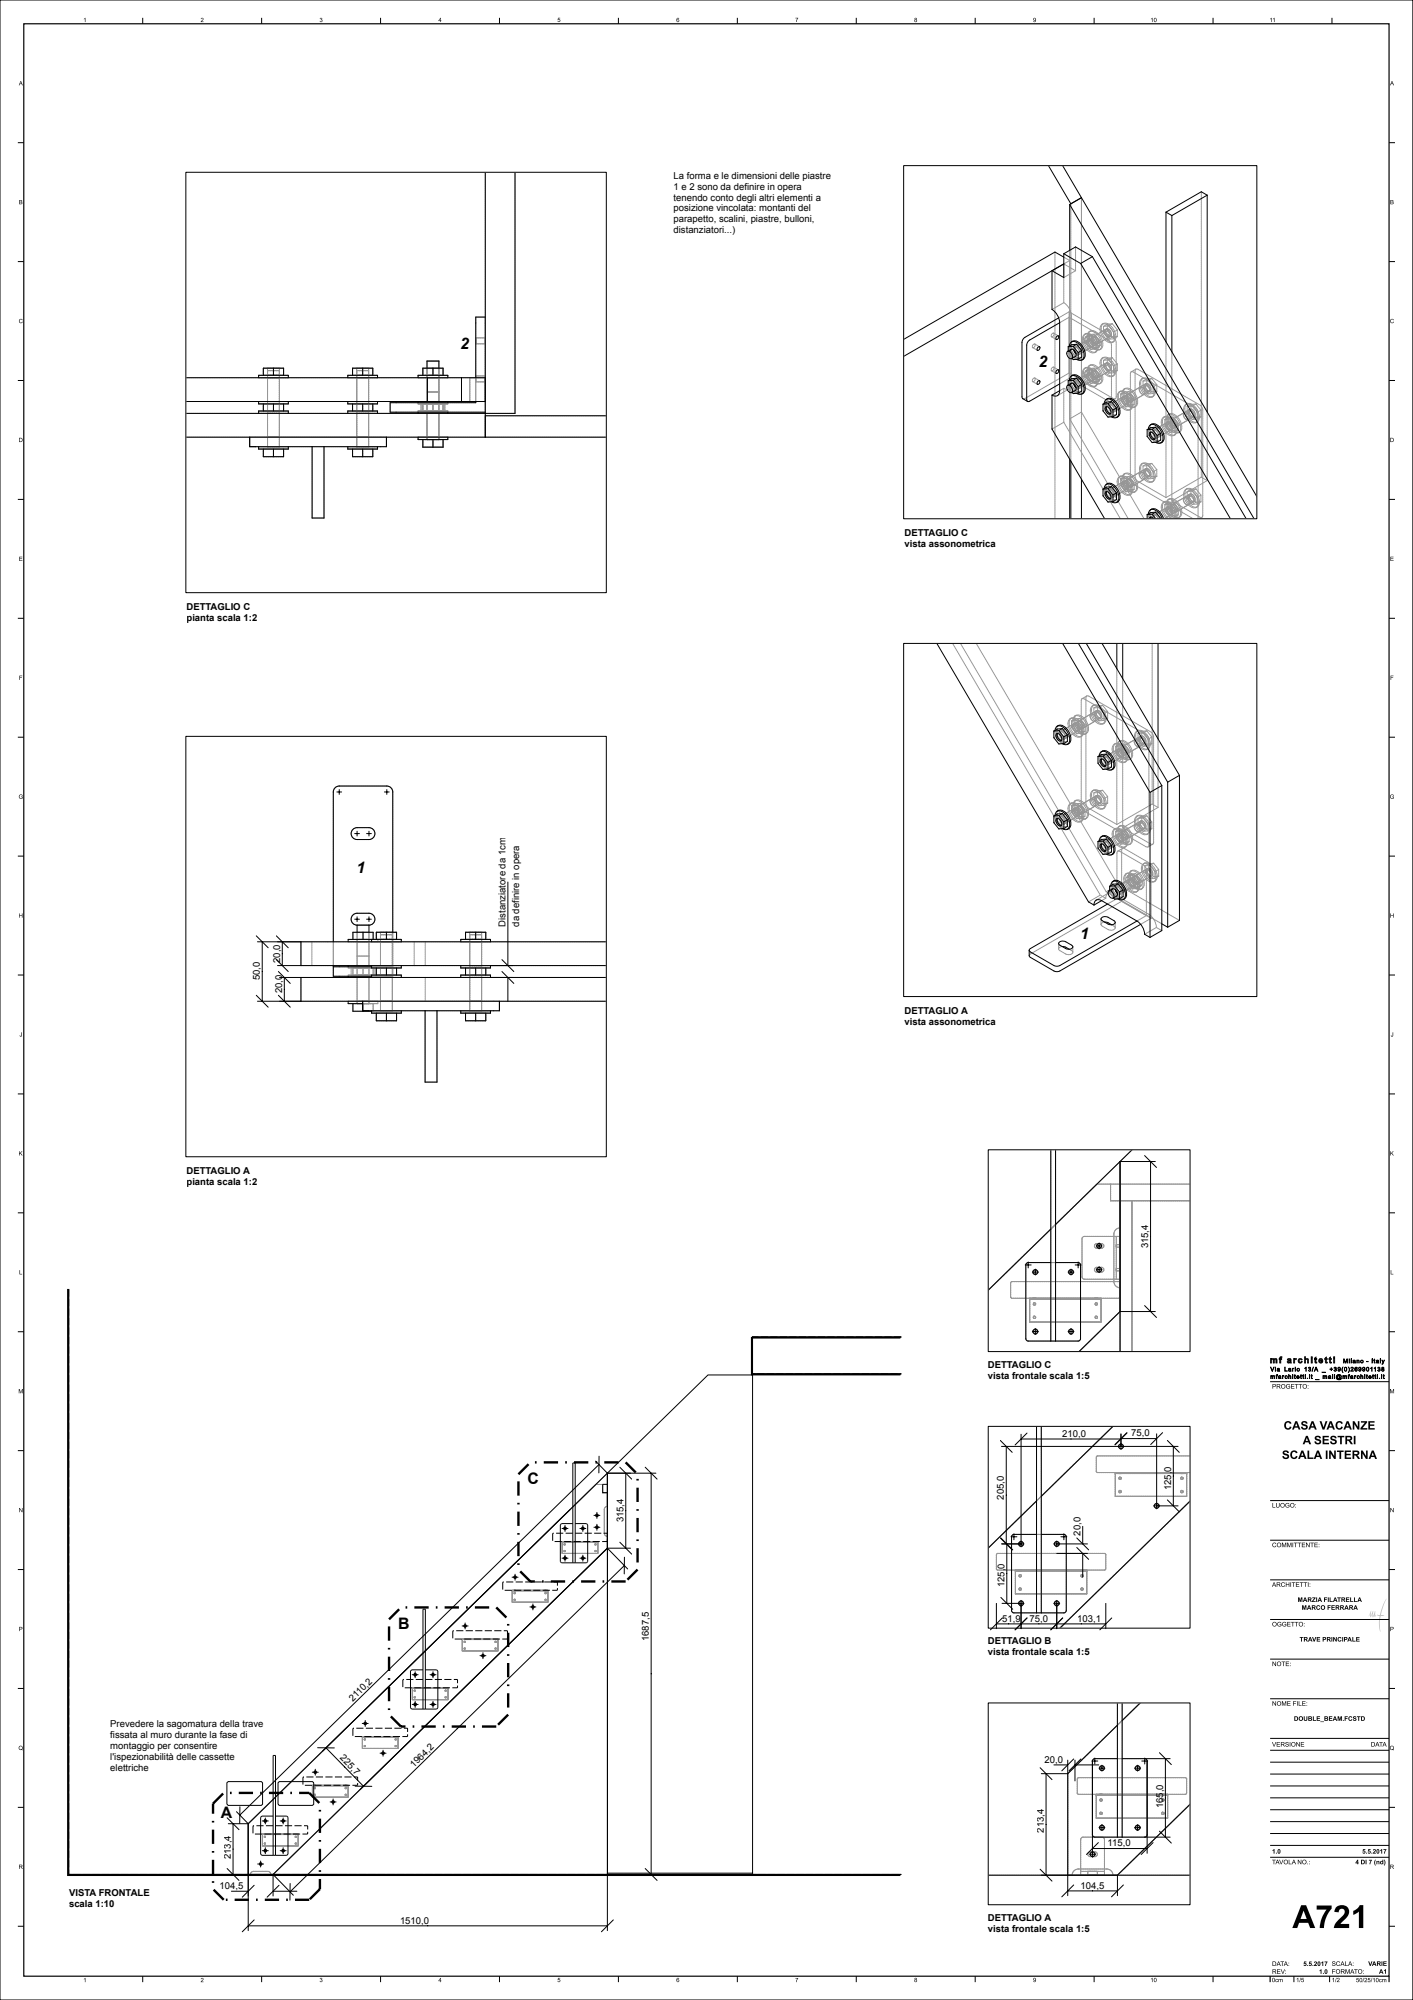
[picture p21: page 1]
104,5 ²¹³,4; 103,1 ¹²⁵,0; Distanziatore da 1cm; VISTA FRONTALE scala 1:10; DETTAGLIO A pianta scala 1:2; DETTAGLIO C pianta scala 1:2; DETTAGLIO A vista assonometrica; DETTAGLIO C vista assonometrica

La forma e le dimensioni delle piastre
1 e 2 sono da definire in opera
tenendo conto degli altri elementi a
posizione vincolata: montanti del
parapetto, scalini, piastre, bulloni,
distanziatori...)

da definire in opera

DETTAGLIO C
vista frontale scala 1:5

DETTAGLIO B

Prevedere la sagomatura della trave
fissata al muro durante la fase di
montaggio per consentire
l'ispezionabilità delle cassette
elettriche

DETTAGLIO A
